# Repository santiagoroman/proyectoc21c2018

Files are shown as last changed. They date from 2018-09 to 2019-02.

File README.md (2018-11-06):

# Proyecto Diseño de Circuitos Electrónicos 1C2018

- Documentos de referencia
- Hojas de datos
- Informe
- Simulaciones
- Mediciones

A considerar a la hora de hacer el proyecto:

- [X] Agregar resistencia en la etapa de salida para regulacion termina

- [X] Separar en el PCB las pistas de entrada de las de salida

- [X] Agregar capacitores de 1000uF aprox con la alimentacion de manera tal de no exigir tanto a la fuente

- [X] Asegurarse que el camino de realimentacion (entre salida y entrada al buffer) sea lo más corto posible en el PCB

- [ ] Proteccion de continua en la carga

- [ ] Proteccion de exceso de corriente a la salida (foldback o comun, reusando la resistencia anterior)

Progreso de TP V2.0<br />
Progress<br />
<br />
Tener en cuenta que la vez pasada se nos quemaron muchos BD y TIP, entonces es mejor que solo tenga pistas de un lado. Asi no desoldamos mucho cada vez<br />

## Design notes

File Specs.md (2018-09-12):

*Especificaciones amplificador CF:*

A continuación se dan las especificaciones mínimas que debe cumplir el prototipo al momento de su presentación. 
El resto de las especificaciones son abiertas y deberán ser definidas en su totalidad por los estudiantes como
parte del diseño concepual del proyecto, tanto a partir de las especificaciones dadas como de los requerimientos 
para sistemas de audio comerciales.

Potencia:
- [X] 40 WRMS @ 8 Ohm
 
- [X] Ancho de banda de potencia > 500 kHz.
 
- [X] SNR > 80dB
 
- [X] Factor de amortiguamiento > 100
 
- THD:
- [X] 1kHz & 1W: 0.02%
- [X] 1kHz & 40W: 0.1%
 
- [ ] IMD (SMPTE) <- 70dB

Nota1: La utilización de un servo de DC es obligatorio.

Nota2: Se requiere un 50% del circuito con montaje SMD.

Nota3:La etapa de salida debe ser Pseudo-Darlington.

Nota4: Dado que se requiere un sistema DC servo en el diseño, el acoplamiento de la señal de entrada
debe hacerse sin capacitores, lo que significa “ningún capacitor en el camino de la señal desde la entrada hasta la carga”. 
Notar que esto implica que tampoco haya capacitores de desacople en el lazo de realimentación principal 
(el otro lazo es del DC servo)

| 	 | Simulacion | Mediciones  |
|--- |:---:| ---:|
| Ancho de Banda| 1.22MHz | NM |
| SNR | 116*dB | NM |
| BW potencia | 608*kHz | NM |
| Potencia RMS  | 40 W | NM |
| Vin | 1V | NM |
| THD 1kHz@1W | 0.000111* | NM |
| THD 1kHz@40W  | 0.036* | NM |
| Slew Rate | | NM |
| Ganancia | 25.02 | NM |

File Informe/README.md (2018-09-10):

# Cosas del informe

El informe esta hecho en LaTeX y principalmente fue realizado utilizando Overleaf.

En esta carpeta se pueden encontrar los archivos fuentes de cosas como graficos para el informe realizados en XCircuit, codigo python para generar graficos en base a los csv obtenidos de un osciloscopio con el que realizamos mediciones, etc.

Respecto de las extensiones de los archivos, se pueden distinguir a los archivos fuentes del programa con el que se generaron de la siguiente manera:

- `.svg` Archivo creado con [Inkscape](https://inkscape.org)
- `.ps` Archivo creado con [XCircuit](http://opencircuitdesign.com/xcircuit/)

Información de interés:

- [Tutorial de XCircuit](http://opencircuitdesign.com/xcircuit/tutorial/tutorial.html)

- XCircuit trabaja con archivos PostScript (extensión `.ps`), para poder trabajar facilmente con LaTeX es necesario convertirlo a pdf. Para esto lo que yo hago es ejecutar dos comandos: `ps2pdf input.ps output.pdf` (convierte de ps a pdf) y luego `pdfcrop -margins 5 input.pdf output.pdf` (para asegurarme que no haya espacio blanco en el pdf)

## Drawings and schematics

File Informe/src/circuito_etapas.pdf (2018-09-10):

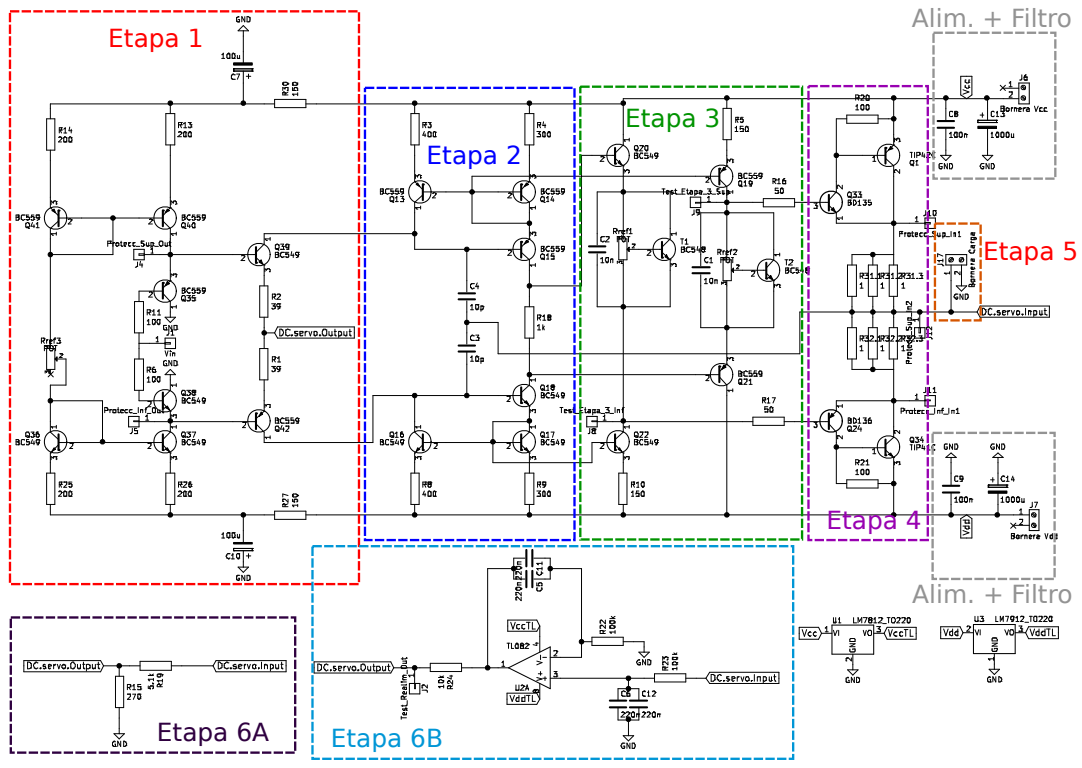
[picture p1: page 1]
Etapa 1; Etapa 2; Etapa 3; Etapa 4; Etapa 5; Etapa 6A; Etapa 6B; Alim. + Filtro

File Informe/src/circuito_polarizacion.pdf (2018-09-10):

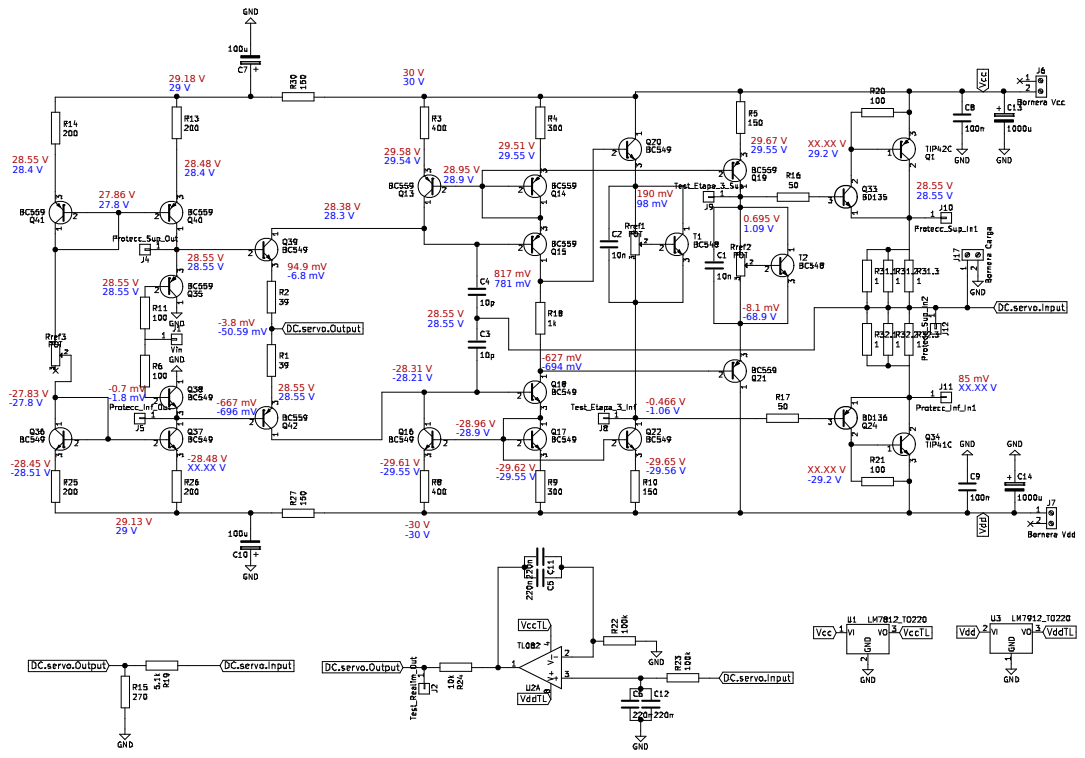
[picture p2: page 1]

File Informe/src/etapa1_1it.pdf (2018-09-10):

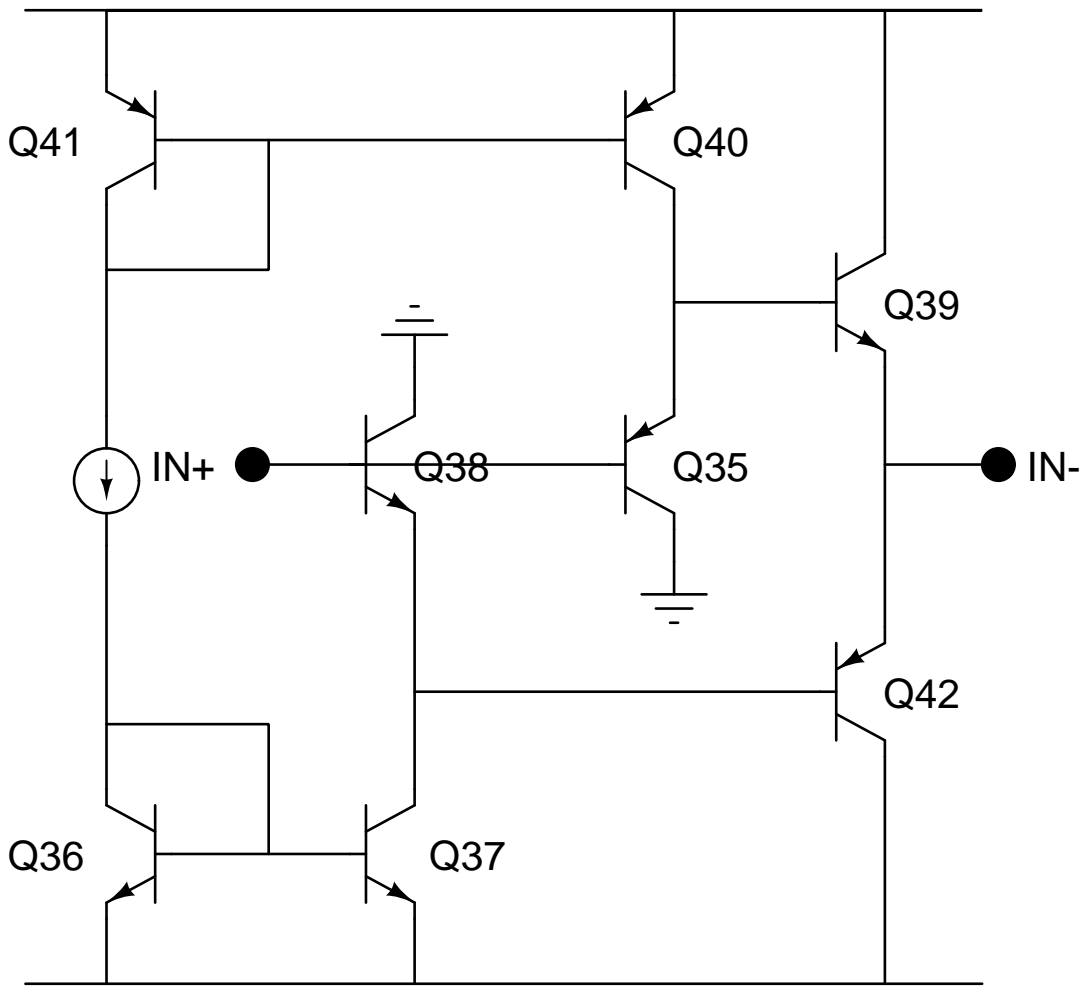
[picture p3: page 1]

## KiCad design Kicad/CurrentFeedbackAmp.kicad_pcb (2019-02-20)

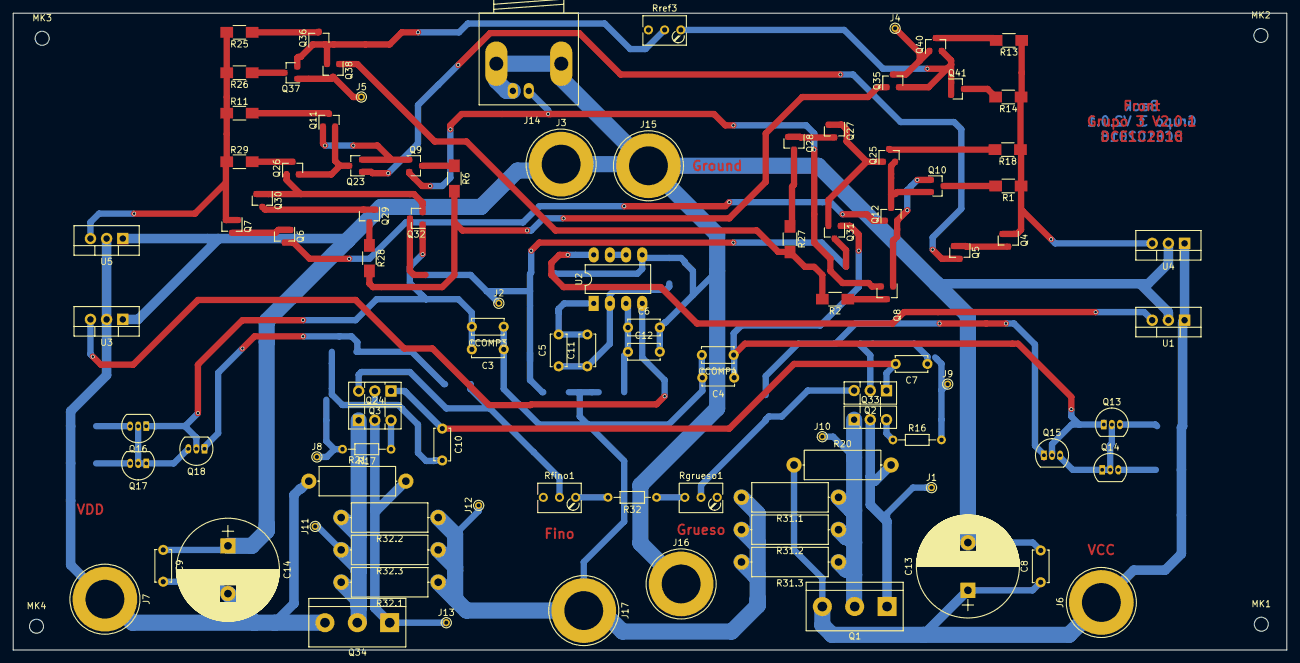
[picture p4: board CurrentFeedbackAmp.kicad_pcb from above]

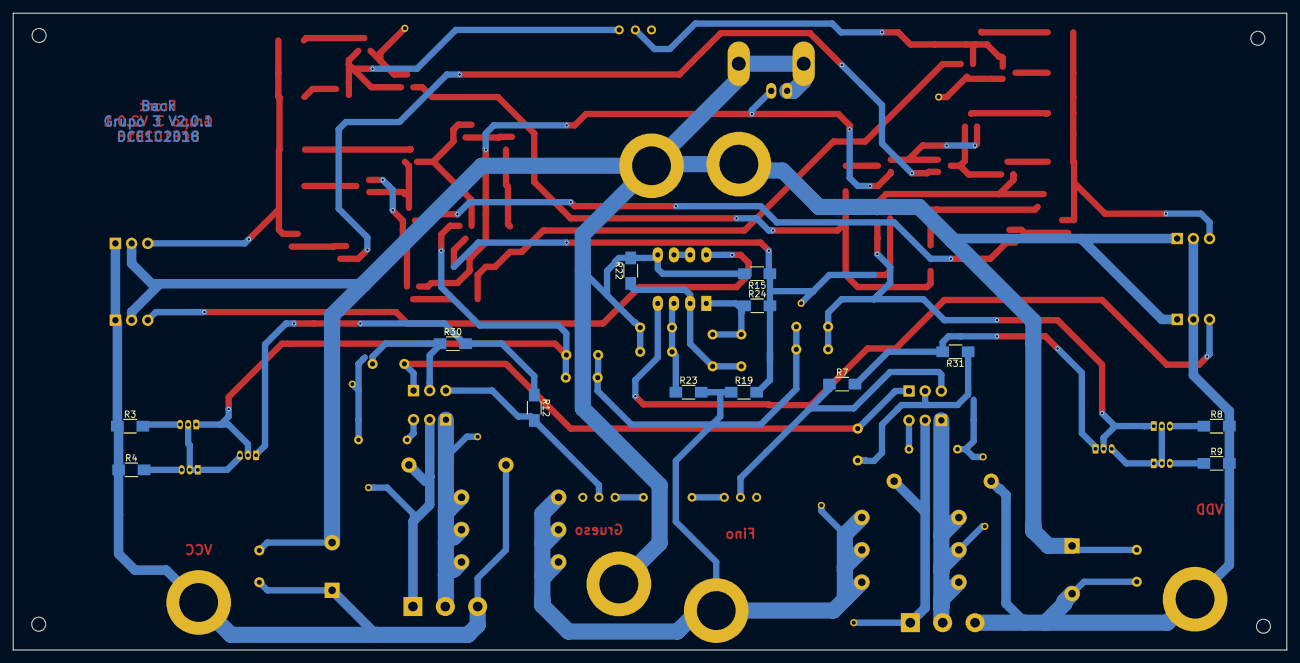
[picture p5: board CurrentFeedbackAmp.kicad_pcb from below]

Board: 2 copper layers, 200.0 x 100.0 mm, 115 parts (13 on the bottom side), 69 nets.

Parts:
C3, C4: 10p; C_Disc_D5.0mm_W2.5mm_P5.00mm
C5, C6, C11, C12: 470n; C_Disc_D5.0mm_W2.5mm_P5.00mm
C7, C8, C9, C10: 100n; C_Disc_D5.0mm_W2.5mm_P5.00mm
C13, C14: 1000u; CP_Radial_D16.0mm_P7.50mm
CCOMP3, CCOMP4: 10p; C_Disc_D5.0mm_W2.5mm_P5.00mm
J1, J8, J13: Test_Etapa_3_Inf; PINTST
J2: Test_Realim_Out; PINTST
J3: Salida masa1; Banana_Jack_1Pin
J4: Protecc_Sup_Out; PINTST
J5: Protecc_Inf_Out; PINTST
J6: Conector Vcc; Banana_Jack_1Pin
J7: Conector Vdd; Banana_Jack_1Pin
J9: Test_Etapa_3_Sup; PINTST
J10: Protecc_Sup_In1; PINTST
J11: Protecc_Inf_In1; PINTST
J12: Protecc_Sup_In2; PINTST
J14: Entrada; BNC_Socket_TYCO-AMP_LargePads
J15: Salida masa2; Banana_Jack_1Pin
J16: Salida tierra; Banana_Jack_1Pin
J17: Salida senal; Banana_Jack_1Pin
MK1, MK2, MK3, MK4: Mounting_Hole; MountingHole_2.2mm_M2
Q1: TIP42C; TerminalBlock_bornier-3_P5.08mm
Q2, Q33: BD135; TO-126_Vertical
Q3, Q24: BD136; TO-126_Vertical
Q4, Q5, Q8, Q11, Q23, Q26, Q27, Q28, Q31, Q36, Q37, Q38: BC848; SOT-23
Q6, Q7, Q9, Q10, Q12, Q25, Q29, Q30, Q32, Q35, Q40, Q41: BC858; SOT-23
Q13, Q14, Q15: BC559; TO-92_Inline_Narrow_Oval
Q16, Q17, Q18: BC549; TO-92_Inline_Narrow_Oval
Q34: TIP41C; TerminalBlock_bornier-3_P5.08mm
R1, R11, R18, R29: 100; R_1206_HandSoldering
R2, R6, R27, R28: 50; R_1206_HandSoldering
R3, R4, R8, R9: 150; R_1206_HandSoldering
R7, R12: 1k; R_1206_HandSoldering
R13, R14, R25, R26: 200; R_1206_HandSoldering
R15, R24: 330; R_1206_HandSoldering
R16, R17: 50; R_Axial_DIN0204_L3.6mm_D1.6mm_P7.62mm_Horizontal
R19: 3.9k; R_1206_HandSoldering
R20, R21: 100; R_Axial_DIN0414_L11.9mm_D4.5mm_P15.24mm_Horizontal
R22, R23: 100k; R_1206_HandSoldering
R30, R31: 5.1; R_1206_HandSoldering
R31.1, R31.2, R31.3, R32.1, R32.2, R32.3: 1; R_Axial_DIN0414_L11.9mm_D4.5mm_P15.24mm_Horizontal
R32: 1k; R_Axial_DIN0204_L3.6mm_D1.6mm_P7.62mm_Horizontal
Rfino1: POT; Potentiometer_Trimmer_Bourns_3266Y
Rgrueso1: POT; Potentiometer_Trimmer_Bourns_3266Y
Rref3: POT; Potentiometer_Trimmer_Bourns_3266Y
U1: LM7812_TO220; TO-220_Vertical
U2: TL082; DIP-8_W7.62mm_LongPads
U3: LM7912_TO220; TO-220_Vertical
U4: LM7805_TO220; TO-220_Vertical
U5: LM7905_TO220; TO-220_Vertical

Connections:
GND: C6.2, C8.2, C9.1, C12.2, C13.2, C14.1, J3.1, J14.2, J15.1, J16.1, R15.2, R22.2, U1.2, U2.5, U3.1, U4.2, U5.1
Ireference1: Q35.1, R6.2, R28.2
Ireference2: Q38.1, R2.2, R27.2
unnamed: C3.2, CCOMP3.2, Q16.1, Q18.2, Q32.1
unnamed: C4.1, CCOMP4.1, Q13.1, Q15.2, Q31.1
unnamed: C7.1, Q2.2, R30.1
unnamed: C7.2, C10.1, Q2.1, Q3.1
unnamed: C10.2, Q3.2, R31.1
unnamed: C5.1, C11.1, R22.1, U2.2
unnamed: C5.2, C11.2, R24.1, U2.1
unnamed: C6.1, C12.1, R23.1, U2.3
unnamed: J1.1, Q1.1, Q33.2, R20.2
unnamed: J4.1, Q35.3, Q40.1
unnamed: J5.1, Q37.1, Q38.3
unnamed: J8.1, R17.2
unnamed: J9.1, R16.2
unnamed: J10.1, Q1.2, Q33.1, R31.1.1, R31.2.1, R31.3.1
unnamed: J11.1, Q24.1, Q34.2, R32.1.2, R32.2.2, R32.3.2
unnamed: J13.1, Q24.2, Q34.1, R21.2
unnamed: Q2.3, R12.2, Rgrueso1.2
unnamed: Q3.3, R7.1, Rfino1.2
unnamed: Q4.3, Q5.1, Q5.2
unnamed: Q6.1, Q6.2, Q7.3
unnamed: Q8.3, R2.1
unnamed: Q9.3, R6.1
unnamed: Q8.1, Q10.1, Q12.2
unnamed: Q10.2, Q12.3, Q25.2
unnamed: Q10.3, R1.2
unnamed: Q9.1, Q11.1, Q23.2
unnamed: Q11.2, Q23.3, Q26.2
unnamed: Q11.3, R11.2
unnamed: Q6.3, Q12.1
unnamed: Q13.2, Q14.1, Q14.2, Q15.3
unnamed: Q13.3, R3.2
unnamed: Q14.3, R4.2
unnamed: Q15.1, R12.1, R30.2
unnamed: Q16.2, Q17.1, Q17.2, Q18.3
unnamed: Q16.3, R8.1
unnamed: Q17.3, R9.1
unnamed: Q18.1, R7.2, R31.2
unnamed: Q5.3, Q23.1
unnamed: Q24.3, R17.1
unnamed: Q25.1, Q27.1, Q27.2, Q31.2
unnamed: Q25.3, R18.2
unnamed: Q26.1, Q30.1, Q30.2, Q32.2
unnamed: Q26.3, R29.2
unnamed: Q27.3, Q28.1, Q28.2
unnamed: Q28.3, R27.1
unnamed: Q29.1, Q29.2, Q30.3
unnamed: Q29.3, R28.1
unnamed: Q33.3, R16.1
unnamed: Q35.2, Q40.2, Q41.1, Q41.2, Rref3.1
unnamed: Q36.1, Q36.2, Q37.2, Q38.2, Rref3.2
unnamed: Q36.3, R25.1
unnamed: Q37.3, R26.1
unnamed: Q40.3, R13.2
unnamed: Q41.3, R14.2
unnamed: R32.1, Rgrueso1.3
unnamed: R32.2, Rfino1.1
unnamed: U2.6, U2.7
Vcc: C8.1, C13.1, J6.1, Q1.3, R3.1, R4.1, R20.1, U1.1, U4.1
Vcc5: Q4.1, Q4.2, R1.1, R13.1, R14.1, R18.1, U4.3
VccTL: U1.3, U2.8
Vdd: C9.2, C14.2, J7.1, Q34.3, R8.2, R9.2, R21.1, U3.2, U5.2
Vdd5: Q7.1, Q7.2, R11.1, R25.2, R26.2, R29.1, U5.3
VddTL: U2.4, U3.3
Vin+: J14.1, Q8.2, Q9.2
Vin-: J2.1, Q31.3, Q32.3, R15.1, R19.2, R24.2
Vout: C3.1, C4.2, CCOMP3.1, CCOMP4.2, J12.1, J17.1, R19.1, R23.2, R31.1.2, R31.2.2, R31.3.2, R32.1.1, R32.2.1, R32.3.1

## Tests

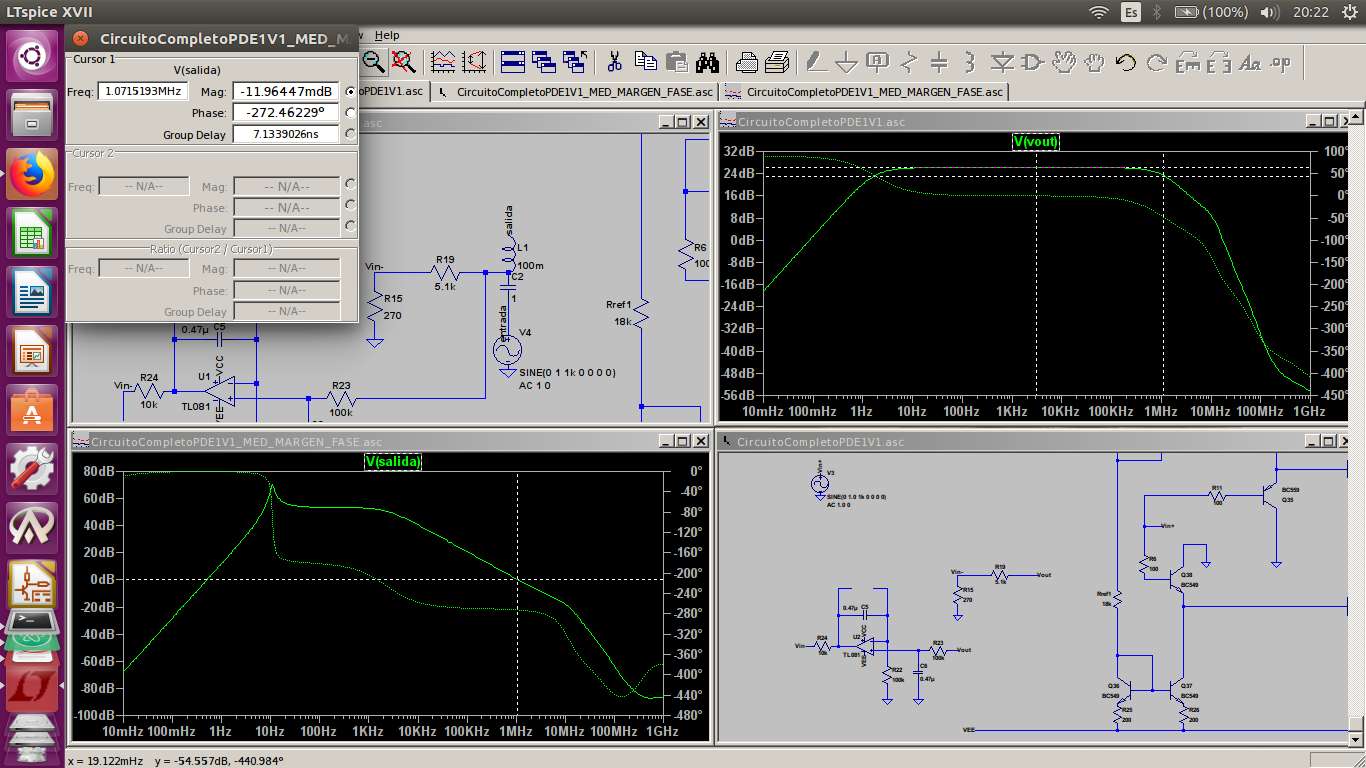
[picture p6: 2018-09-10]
Simulaciones/resultados/margen_de_fase_y_ancho_de_banda.png

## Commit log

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2018-09-10 circuito ahora esta apareado y anda todo, esquematico de kicad apenas empezado
    [CurrentFeedbackAmp.kicad_pcb, CurrentFeedbackAmp.sch]
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2018-09-10 Cambios en el servo, but not working yet
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2018-09-10 Circuito casi completo en kicad y testeo de proteccion con foldback
    [CurrentFeedbackAmp.sch]
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2018-09-10 Va el esquematico de KiCAD con nombres y numeros
    [CurrentFeedbackAmp.sch]
2018-09-10 va el esquematico incluyendo las resistencias de potencia
    [CurrentFeedbackAmp.sch]
2018-09-10 Casi todos los componentes con su respectivo modelo asociado
    [CurrentFeedbackAmp.sch]
2018-09-10 Agregué el borde de la placa
    [CurrentFeedbackAmp.kicad_pcb]
2018-09-10 Alinee los transistores en uno de los extremos del pcb
    [CurrentFeedbackAmp.kicad_pcb]
2018-09-10 Ahora el PCB tiene agujeros para montar la placa y modifique el modelo de los pines
    [CurrentFeedbackAmp.kicad_pcb, CurrentFeedbackAmp.sch]
2018-09-10 PCB: Bornera, tierras y nombre a los pines
    [CurrentFeedbackAmp.kicad_pcb, CurrentFeedbackAmp.sch]
2018-09-10 Cambio modelo de capacitores electroliticos
    [CurrentFeedbackAmp.kicad_pcb, CurrentFeedbackAmp.sch]
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2018-09-10 termindado el acomodo de componentes kicad
    [CurrentFeedbackAmp.kicad_pcb]
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2018-09-10 Kicad compatibility to 4.0.7
    [CurrentFeedbackAmp.kicad_pcb]
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2018-09-10 Agregue reguiladores al kicad y complete las conexiones de los pines del tl082
    [CurrentFeedbackAmp.kicad_pcb, CurrentFeedbackAmp.sch]
2018-09-10 Conexion correcta de pines inutilizados del TL082 y la guia que explica por que
    [CurrentFeedbackAmp.kicad_pcb, CurrentFeedbackAmp.sch]
2018-09-10 Elimine algunos pins que no deberian ir porque van a ser conectados con pistas
    [CurrentFeedbackAmp.kicad_pcb, CurrentFeedbackAmp.sch]
2018-09-10 Va la primera etapa de Rooteooooo
    [CurrentFeedbackAmp.kicad_pcb]
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2018-09-10 Arreglo errores en el README
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2018-09-12 ya llevamos el esquematico al KiCAD V2.0 Todavia hay que revisar el esquematico
    [CurrentFeedbackAmp.sch]
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2018-09-19 Armamos con nico el SCH en el KiCAD
    [CurrentFeedbackAmp.sch]
2018-09-19 se agrega el pin de entrada, hay que ver si ya podemos empezar con el PCB
    [CurrentFeedbackAmp.sch]
2018-09-22 Conectores de tensiones de alimentacion ahora son banana y el conector de la entrada ahora es un BNC hembra
    [CurrentFeedbackAmp.sch]
2018-09-22 Modificado conector bornera de salida por dos banana
    [CurrentFeedbackAmp.sch]
2018-09-22 Cambiados transistores de fuente de corriente por sus equivalentes SMD
    [CurrentFeedbackAmp.sch]
2018-09-22 Cambios en transitores de etapa siguiente a la fuente de corriente por SMD
    [CurrentFeedbackAmp.sch]
2018-09-22 Cambiadas resistencias SMD por un modelo SMD que es mas grande asi es mas facil de soldar. Tambier cambiamos las resistencias del cuasidarlington de 100 ohm para que sean THT
    [CurrentFeedbackAmp.sch]
2018-09-22 Agregue los modelos para las nuevas resistencias del (ahora unico) multiplicador de Vbe
    [CurrentFeedbackAmp.sch]
2018-09-22 Arreglo error en conectores banana de tensiones de alimentacion que tenian el modelo erroneo
    [CurrentFeedbackAmp.kicad_pcb, CurrentFeedbackAmp.sch]
2018-09-22 Bug fixing
    [CurrentFeedbackAmp.kicad_pcb]
2018-10-10 movi un par de componentes para despejar la placa
    [CurrentFeedbackAmp.kicad_pcb]
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2018-10-13 etapa uno terminada, queda mucho lugar para lo demas. Centro reservado para configuracion estrella
    [CurrentFeedbackAmp.kicad_pcb]
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2018-10-15 Todos los componentes colocados en la placa, faltan hacer mejoras pero al menos demuestra que es posible terminarla :D
    [CurrentFeedbackAmp.kicad_pcb]
2018-10-15 Arreglo una conexion a los TL que estaba en la capa frontal pero tenia que ir en la trasera (ese truquito solo sirve para capacitores y resistencias tht)
    [CurrentFeedbackAmp.kicad_pcb]
2018-10-15 Algunas conexiones mas, incluida la de retorno de masa que va por el "medio" de la placa
    [CurrentFeedbackAmp.kicad_pcb]
2018-10-16 Avance con ensanchado, acomodado de pistas y reposicionamiento de los LM
    [CurrentFeedbackAmp.kicad_pcb]
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2018-10-18 Ultima conexion hecha, era un pedacito practicamente invisible...
    [CurrentFeedbackAmp.kicad_pcb]
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2018-10-28 reparacion version vieja vs nueva de Kicad. Si van a hacer algo gratuito y libre por lo menos haganlo bien!
    [CurrentFeedbackAmp.kicad_pcb, CurrentFeedbackAmp.sch]
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2018-10-29 ya esta colocado los potes de VBE mejoramos posicion de realimentacion
    [CurrentFeedbackAmp.kicad_pcb]
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2018-11-04 Modifique algunas conexiones en transistores para que la conexion en si entre pista y transitor sea en el back en vez del front, obviamente que para lograrlo tuve que agregar algunas vias mas
    [CurrentFeedbackAmp.kicad_pcb]
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2018-11-04 Mejoras en dos caminos para evitar que se solapen con otras pistas
    [CurrentFeedbackAmp.kicad_pcb]
2018-11-04 Se agregan textos para saber mejor los puntos importantes
    [CurrentFeedbackAmp.kicad_pcb]
2018-11-04 Mayor separacion entre J16 y J17 por seguridad y reactive las diferentes capas
    [CurrentFeedbackAmp.kicad_pcb]
2018-11-04 Arreglue posicion de los transistores de salida
    [CurrentFeedbackAmp.kicad_pcb]
2018-11-05 Mala mia, al final estaba bien el sentido de los transistores de salida asi que vuelvo atras
    [CurrentFeedbackAmp.kicad_pcb]
2018-11-06 Movimos para arriba los transistores del multiplicador asi podemos llegar a tener una unica chapita
    [CurrentFeedbackAmp.kicad_pcb]
2018-11-06 Ya va quedando mucho mas prolijo y mas parecido a un amplificador de audio pro
    [CurrentFeedbackAmp.kicad_pcb]
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2019-02-20 va el circuito sin muchas cosas que sobraban
    [CurrentFeedbackAmp.kicad_pcb, CurrentFeedbackAmp.sch]
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
